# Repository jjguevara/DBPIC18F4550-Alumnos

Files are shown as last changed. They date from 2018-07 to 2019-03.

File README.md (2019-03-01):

# DBPIC18F4550-Alumnos
1. Archivos fuente para placa de desarrollo PIC18F4550 de alumnos

2. HIDBootloader.exe, es el programa gestor del bootloader, compatible con Windows 7/8/8.1/10, requiere de .NET Framework 3.5.
En la siguiente página, se muestra un ejemplo de utilización del programa:http://rado.heliohost.org/content_5.htm

3. USB Device - HID - HID Bootloader - C18 - PIC18F4550.hex, es el programa bootloader que debe cargarse en la memoria de programa del microcontrolador usando un programador externo, la placa de desarrollo dispone de un puerto ICSP para este propósito. Programadores compatibles: Pickit 2/3 y Brenner 8.

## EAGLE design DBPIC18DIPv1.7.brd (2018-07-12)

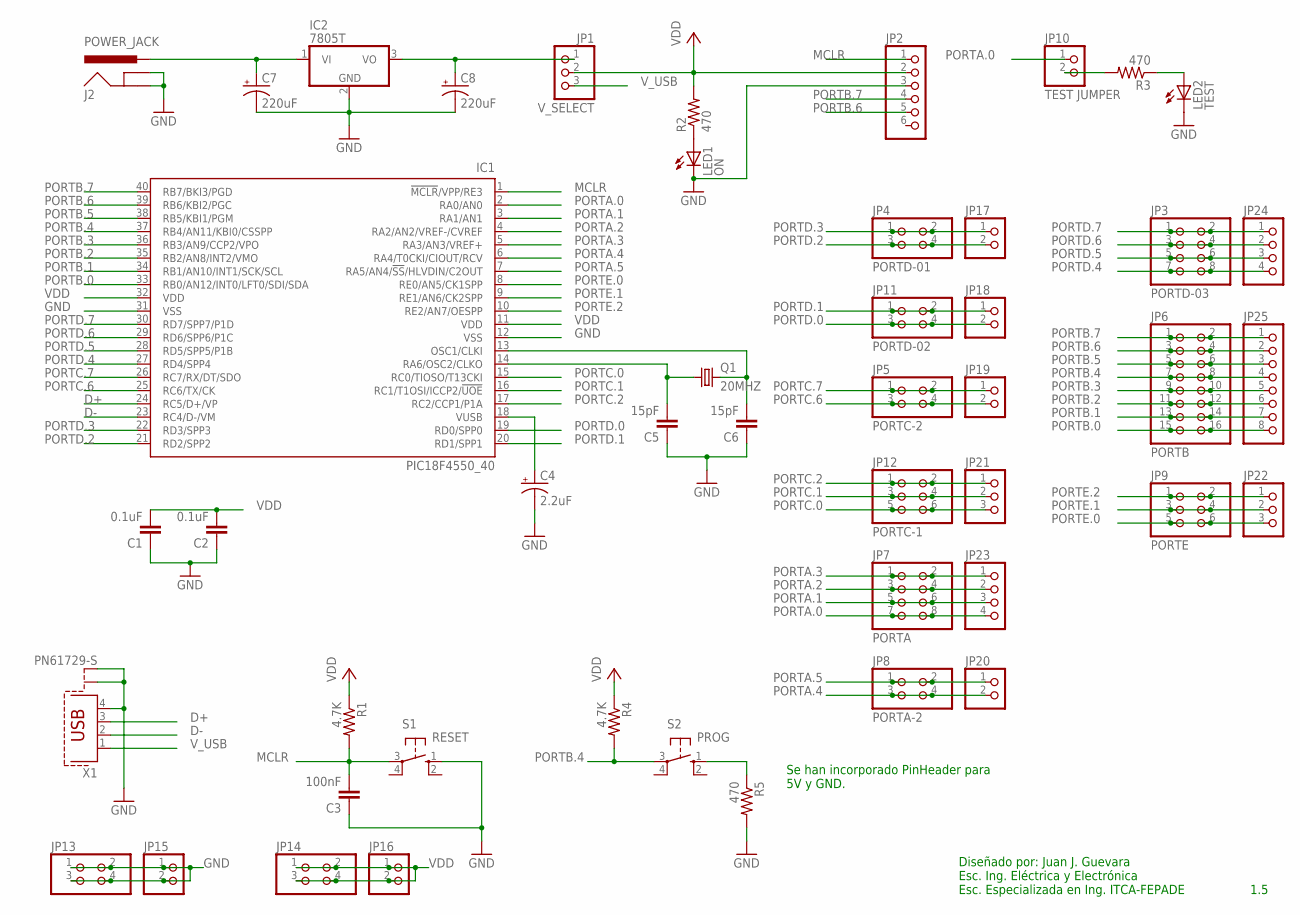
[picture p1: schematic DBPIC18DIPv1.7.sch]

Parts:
C1, C2: 0.1uF; C2.5-2
C3: 100nF; C2.5-2
C4: 2.2uF; E1,8-4
C5, C6: 15pF; C2.5-2
C7: 220uF; E2-5
C8: 220uF; E1,8-4
IC1: PIC18F4550_40; DIL40
IC2: 7805T; TO220H
J2: POWER_JACK; POWER_JACK_PTH
JP1: V_SELECT; 1X03
JP2: PINHD-1X6; 1X06
JP3: PORTD-03; 2X04
JP4: PORTD-01; 2X02
JP5: PORTC-2; 2X02
JP6: PORTB; 2X08
JP7: PORTA; 2X04
JP8: PORTA-2; 2X02
JP9: PORTE; 2X03
JP10: TEST JUMPER; 1X02
JP11: PORTD-02; 2X02
JP12: PORTC-1; 2X03
JP13, JP14: PINHD-2X2; 2X02
JP15, JP16, JP17, JP18, JP19, JP20: PINHD-1X2; 1X02
JP21, JP22: PINHD-1X3; 1X03
JP23, JP24: PINHD-1X4; 1X04
JP25: PINHD-1X8; 1X08
LED1: ON; LED3MM
LED2: TEST; LED3MM
Q1: 20MHZ; HC49/S
R1, R4: 4.7K; 0207/12
R2, R3, R5: 470; 0207/12
S1: RESET; B3F-10XX
S2: PROG; B3F-10XX
X1: PN61729-S

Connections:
D+: IC1.24 (RC5/D+/VP), X1.3
D-: IC1.23 (RC4/D-/VM), X1.2
GND: C1.1, C2.1, C3.1, C4.-, C5.1, C6.1, C7.-, C8.-, IC1.12 (VSS), IC1.31 (VSS), IC2.2 (GND), J2.GND, J2.GNDBREAK, JP2.3, JP13.1, JP13.2, JP13.3, JP13.4, JP15.1, JP15.2, LED1.K (C), LED2.K (C), R5.2, S1.1 (S), X1.4, X1.S1, X1.S2
MCLR: C3.2, IC1.1 (!MCLR!/VPP/RE3), JP2.1, R1.2, S1.3
unnamed: LED2.A, R3.1
unnamed: C6.2, IC1.13 (OSC1/CLKI), Q1.2
unnamed: C5.2, IC1.14 (RA6/OSC2/CLKO), Q1.1
unnamed: C4.+, IC1.18 (VUSB)
unnamed: C8.+, IC2.3 (VO), JP1.1
unnamed: LED1.A, R2.1
unnamed: JP10.2, R3.2
unnamed: R5.1, S2.1 (S)
unnamed: C7.+, IC2.1 (VI), J2.PWR
PORTA.0: IC1.2 (RA0/AN0), JP7.7, JP7.8, JP10.1, JP23.4
PORTA.1: IC1.3 (RA1/AN1), JP7.5, JP7.6, JP23.3
PORTA.2: IC1.4 (RA2/AN2/VREF-/CVREF), JP7.3, JP7.4, JP23.2
PORTA.3: IC1.5 (RA3/AN3/VREF+), JP7.1, JP7.2, JP23.1
PORTA.4: IC1.6 (RA4/T0CKI/CIOUT/RCV), JP8.3, JP8.4, JP20.2
PORTA.5: IC1.7 (RA5/AN4/!SS!/HLVDIN/C2OUT), JP8.1, JP8.2, JP20.1
PORTB.0: IC1.33 (RB0/AN12/INT0/LFT0/SDI/SDA), JP6.15, JP6.16, JP25.8
PORTB.1: IC1.34 (RB1/AN10/INT1/SCK/SCL), JP6.13, JP6.14, JP25.7
PORTB.2: IC1.35 (RB2/AN8/INT2/VMO), JP6.11, JP6.12, JP25.6
PORTB.3: IC1.36 (RB3/AN9/CCP2/VPO), JP6.9, JP6.10, JP25.5
PORTB.4: IC1.37 (RB4/AN11/KBI0/CSSPP), JP6.7, JP6.8, JP25.4, R4.2, S2.3
PORTB.5: IC1.38 (RB5/KBI1/PGM), JP6.5, JP6.6, JP25.3
PORTB.6: IC1.39 (RB6/KBI2/PGC), JP2.5, JP6.3, JP6.4, JP25.2
PORTB.7: IC1.40 (RB7/BKI3/PGD), JP2.4, JP6.1, JP6.2, JP25.1
PORTC.0: IC1.15 (RC0/TIOSO/T13CKI), JP12.5, JP12.6, JP21.3
PORTC.1: IC1.16 (RC1/T1OSI/ICCP2/!UOE), JP12.3, JP12.4, JP21.2
PORTC.2: IC1.17 (RC2/CCP1/P1A), JP12.1, JP12.2, JP21.1
PORTC.6: IC1.25 (RC6/TX/CK), JP5.3, JP5.4, JP19.2
PORTC.7: IC1.26 (RC7/RX/DT/SDO), JP5.1, JP5.2, JP19.1
PORTD.0: IC1.19 (RD0/SPP0), JP11.3, JP11.4, JP18.2
PORTD.1: IC1.20 (RD1/SPP1), JP11.1, JP11.2, JP18.1
PORTD.2: IC1.21 (RD2/SPP2), JP4.3, JP4.4, JP17.2
PORTD.3: IC1.22 (RD3/SPP3), JP4.1, JP4.2, JP17.1
PORTD.4: IC1.27 (RD4/SPP4), JP3.7, JP3.8, JP24.4
PORTD.5: IC1.28 (RD5/SPP5/P1B), JP3.5, JP3.6, JP24.3
PORTD.6: IC1.29 (RD6/SPP6/P1C), JP3.3, JP3.4, JP24.2
PORTD.7: IC1.30 (RD7/SPP7/P1D), JP3.1, JP3.2, JP24.1
PORTE.0: IC1.8 (RE0/AN5/CK1SPP), JP9.5, JP9.6, JP22.3
PORTE.1: IC1.9 (RE1/AN6/CK2SPP), JP9.3, JP9.4, JP22.2
PORTE.2: IC1.10 (RE2/AN7/OESPP), JP9.1, JP9.2, JP22.1
VDD: C1.2, C2.2, IC1.11 (VDD), IC1.32 (VDD), JP1.2, JP2.2, JP14.1, JP14.2, JP14.3, JP14.4, JP16.1, JP16.2, R1.1, R2.2, R4.1
V_USB: JP1.3, X1.1

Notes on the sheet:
Diseñado por: Juan J. Guevara Esc. Ing. Eléctrica y Electrónica Esc. Especializada en Ing. ITCA-FEPADE
1.5
Se han incorporado PinHeader para 5V y GND.

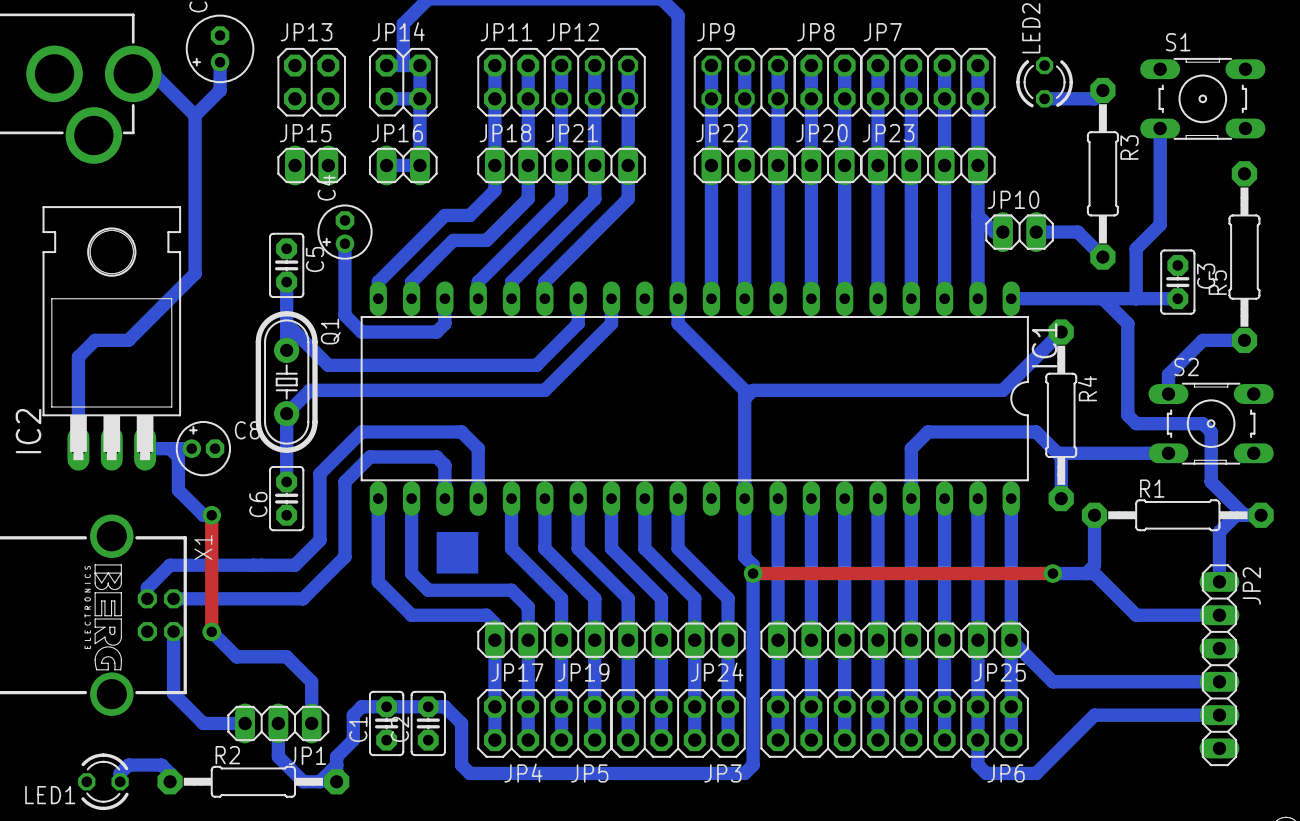
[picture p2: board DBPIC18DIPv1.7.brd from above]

Board: 2 copper layers, 47 parts (0 on the bottom side), 45 nets.

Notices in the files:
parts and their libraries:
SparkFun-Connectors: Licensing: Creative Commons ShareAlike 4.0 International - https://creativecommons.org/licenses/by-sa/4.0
